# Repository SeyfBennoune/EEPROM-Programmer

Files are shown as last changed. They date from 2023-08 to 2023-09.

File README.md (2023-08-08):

# 1. Overview   
  
  This project was part of the Z80 computer project (found in "Z80Computer" repo), where this EEPROM programmer was used intensively in programming that project's EEPROM chips.   
  This project is continuously enhanced whenever possible.  
     
# 2. History and Future enhancement   
   
  ## 2.1 History
  * First, Arduino Uno was used to build the first prototype for this project.  
  * Arduino Uno was replaced later with Arduino Nano for the sake of minimising dimensions.  
  * For GUI, Arduino IDE's serial monitor was used to communicate serially with the device.
  * A C program is built later using gtk toolkit.
  ## 2.2 What's next?
  * Replacing arduino dev board with a microcontroller chip as a chalenge where the level of abstraction is lowered.  
  * Building a GUI using Flutter framework as a learning project.

# 3. Circuit
  ## 3.1 Schematics   
schematics

  ## 3.2 PCB preview
pcbPreview

# 4. GUI   
gui

# 5. Notes
Relevant Kicad files and C program will be uploaded soon.

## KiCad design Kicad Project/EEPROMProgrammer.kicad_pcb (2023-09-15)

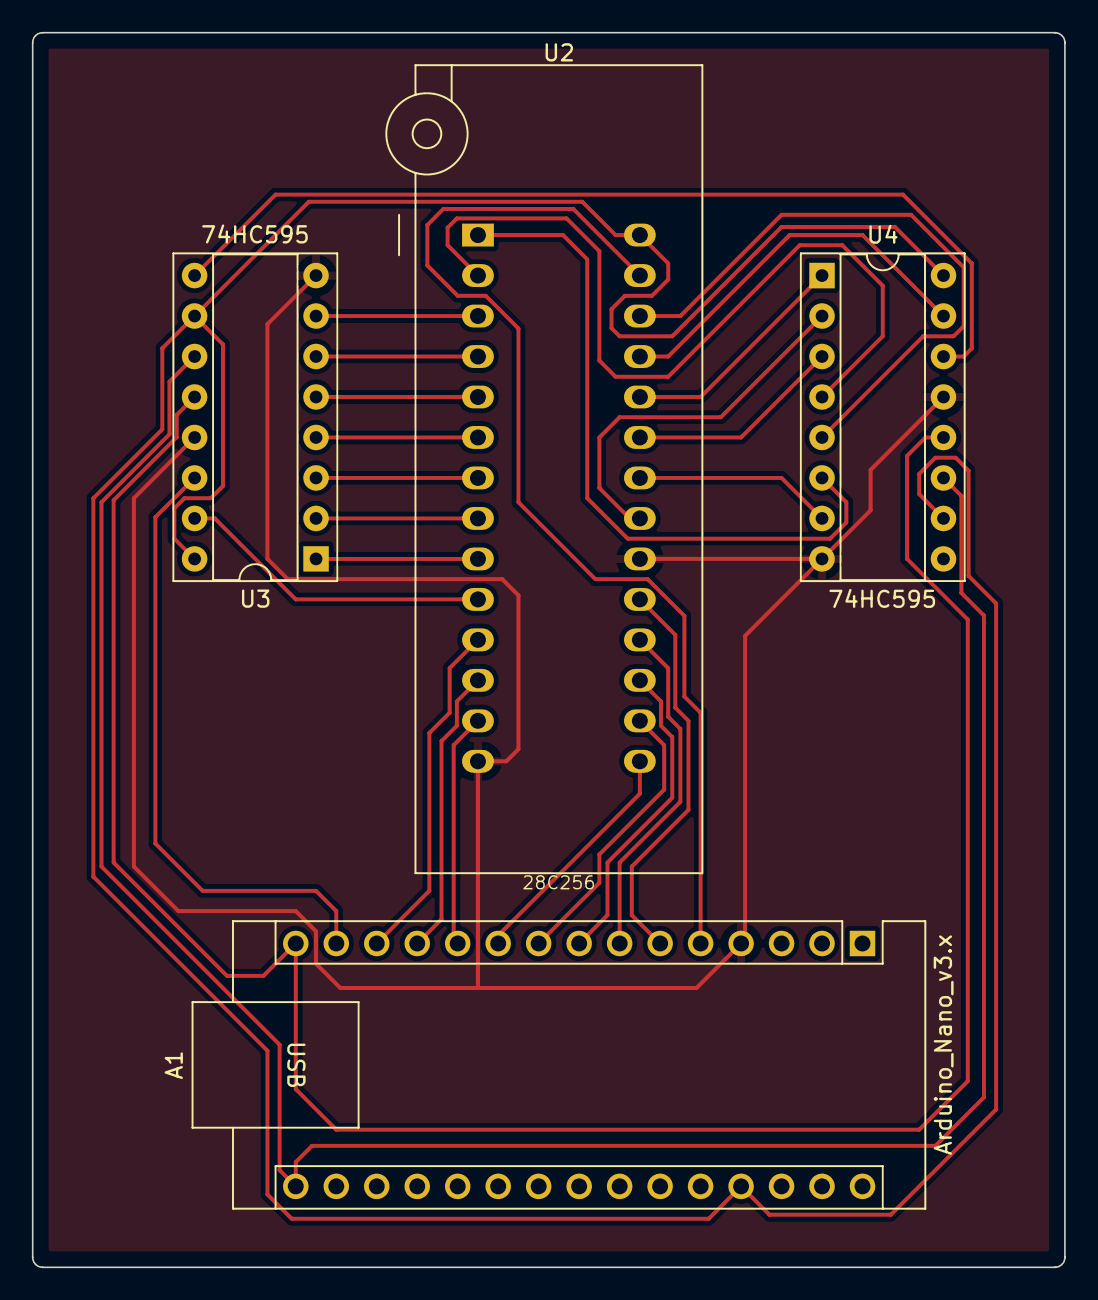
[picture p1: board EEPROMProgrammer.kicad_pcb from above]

Board: 2 copper layers, 64.8 x 77.5 mm, 4 parts (0 on the bottom side), 31 nets.

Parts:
A1: Arduino_Nano_v3.x; Arduino_Nano
U2: 28C256; DIP_Socket-28_W6.9_W7.62_W10.16_W12.7_W13.5_3M_228-4817-00-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
U3, U4: 74HC595; DIP-16_W7.62mm_Socket

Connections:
/A0: U2.10 (A0), U3.15 (QA)
/A1: U2.9 (A1), U3.1 (QB)
/A2: U2.8 (A2), U3.2 (QC)
/A3: U2.7 (A3), U3.3 (QD)
/A4: U2.6 (A4), U3.4 (QE)
/A5: U2.5 (A5), U3.5 (QF)
/A6: U2.4 (A6), U3.6 (QG)
/A7: U2.3 (A7), U3.7 (QH)
/A8: U2.25 (A8), U4.15 (QA)
/A9: U2.24 (A9), U4.1 (QB)
/A10: U2.21 (A10), U4.2 (QC)
/A11: U2.23 (A11), U4.3 (QD)
/A12: U2.2 (A12), U4.4 (QE)
/A13: U2.26 (A13), U4.5 (QF)
/A14: U2.1 (A14), U4.6 (QG)
/D0: A1.13 (D10), U2.11 (D0)
/D1: A1.12 (D9), U2.12 (D1)
/D2: A1.11 (D8), U2.13 (D2)
/D3: A1.10 (D7), U2.15 (D3)
/D4: A1.9 (D6), U2.16 (D4)
/D5: A1.8 (D5), U2.17 (D5)
/D6: A1.7 (D4), U2.18 (D6)
/D7: A1.6 (D3), U2.19 (D7)
/QH': U3.9 (QH'), U4.14 (SER)
GND: A1.4 (GND), U2.14 (GND), U2.20 (~CS), U3.8 (GND), U3.13 (~OE), U4.8 (GND), U4.13 (~OE)
RCLK: A1.15 (D12), U3.12 (RCLK), U4.12 (RCLK)
SER: A1.14 (D11), U3.14 (SER)
SRCLK: A1.16 (D13), U3.11 (SRCLK), U4.11 (SRCLK)
VCC: A1.27 (+5V), U2.28 (VCC), U3.10 (~SRCLR), U3.16 (VCC), U4.10 (~SRCLR), U4.16 (VCC)
~OE: U2.22 (~OE), U4.7 (QH)
~WR: A1.5 (D2), U2.27 (~WE)

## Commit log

2023-09-15 Uploaded Kicad files
2023-09-15 Kicad files uploaded
